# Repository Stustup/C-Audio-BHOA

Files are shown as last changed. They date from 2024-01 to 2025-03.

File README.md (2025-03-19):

# Balanced Headphone Operational Amplifier

A high powered differential headphone amp with a focus on modularity and prototyping. Inspired by the Schiit Audio Magni Heresy.

Picture of the PCB

## Features

- All sections of the amp should be modular (Filter, VA, CA, Output protection)
- All sections should be accessable via pin headers
- Output power >1W per channel

## Schematic

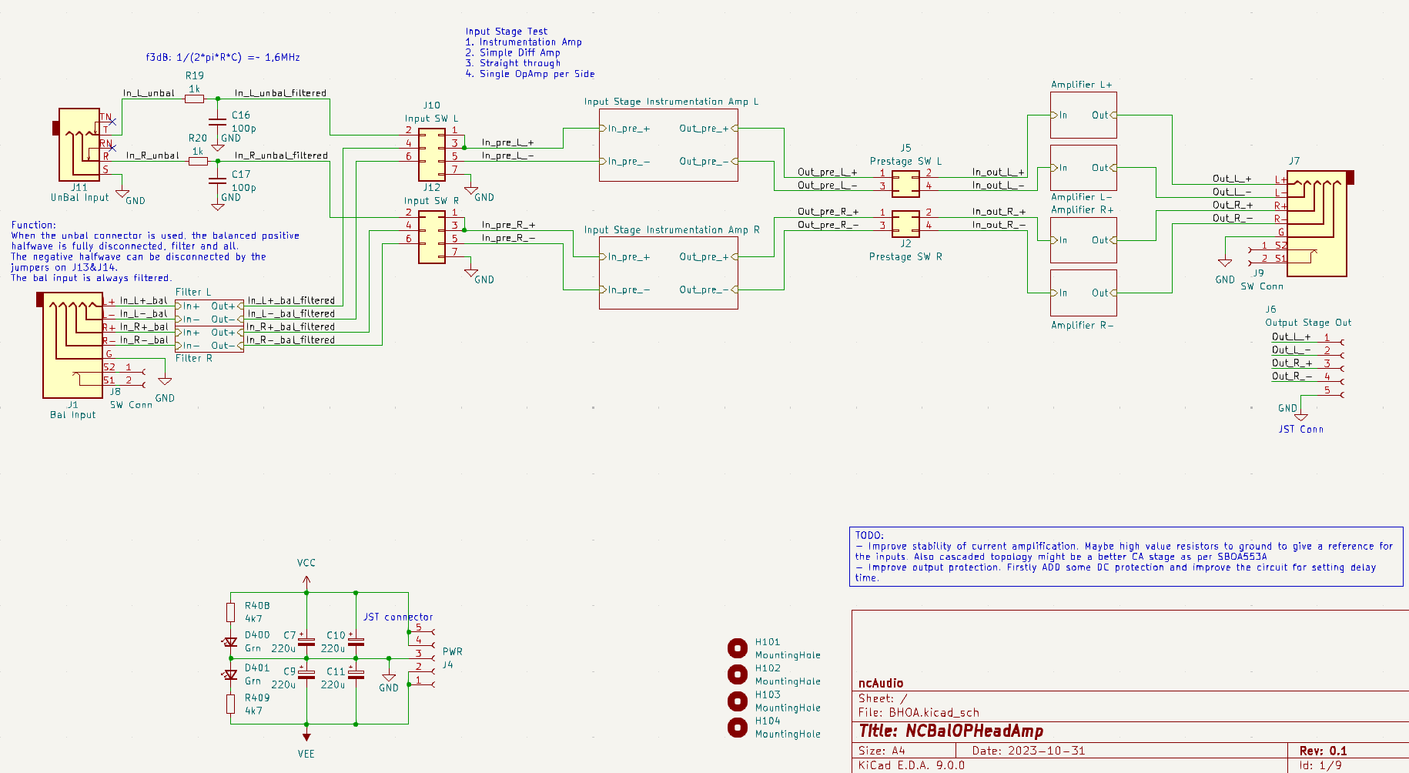
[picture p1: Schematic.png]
Schematic of the Amp


The Amp consists of a simple differential input filter for very high frequency noise, an instrumential amplifier input stage for differential voltage amplification and 8 paralelled opamp sections in buffer topology per channel (of which there are 4 for differential amplification for a total of 16 opamps(!!!). [Mental, I know](http://www.diyaudio.com/archive/blogs/alexcp/attachments/1049d1368388175-ne5532-power-amplifier-ne553205.jpg)). 

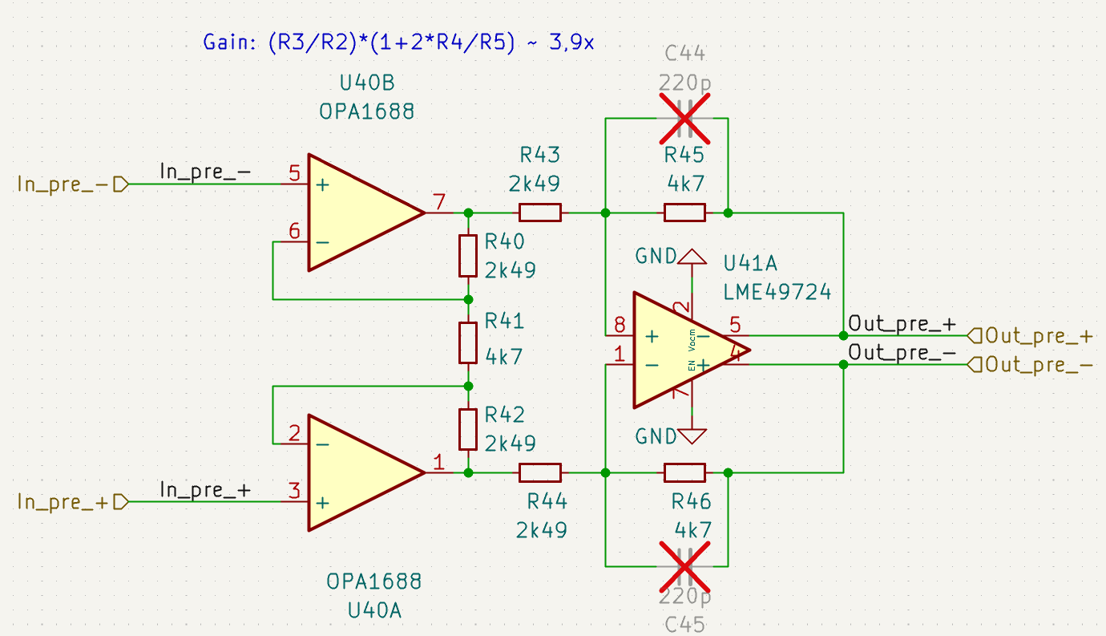
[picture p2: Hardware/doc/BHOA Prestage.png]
Schematic of instrumental amp


The instrumental amplifier in the prestage was chosen, because it is really easy and straight forward to set the gain with just a a single resistor per channel.

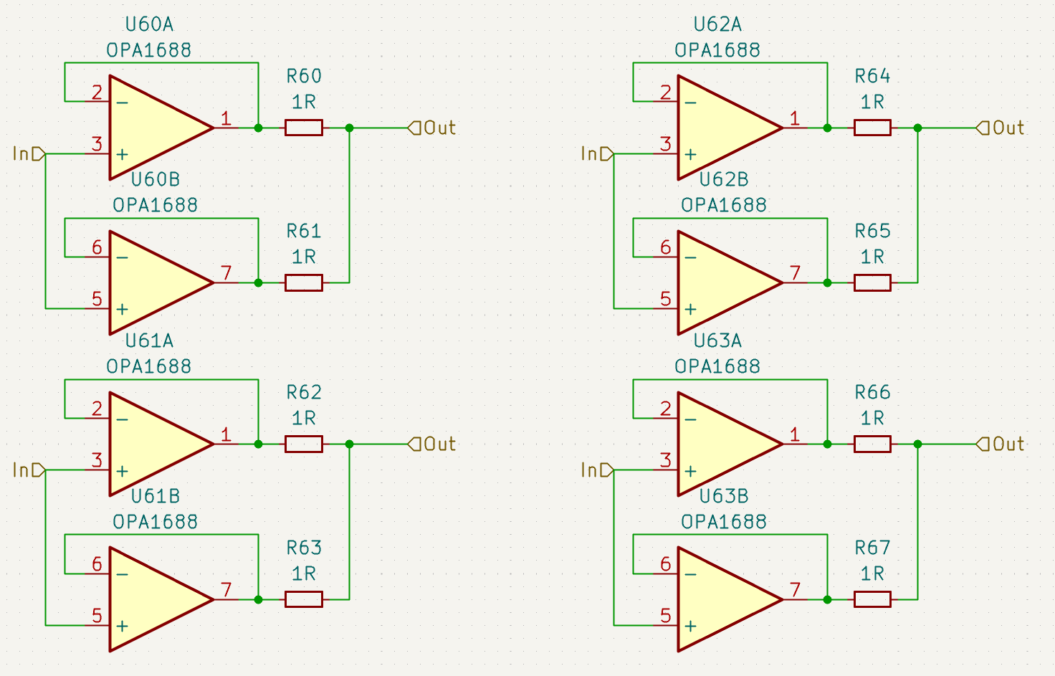
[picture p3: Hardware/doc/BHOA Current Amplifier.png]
Schematic of current amp


Furthermore the output is protected via muting relays driven by a mosfet and a turn on timer for a startup delay. 

The power supply is off board to stay in the limits of JLCPCBs cheap 100x100mm PCB service. It can range from +-5V to +-18V (or how much the Opamps will take). The output relays are 5V, a simple 78l05 so8 IC is supplying them with 5V. 

## TODO

- Improve stability of current amplification. Maybe high value resistors to ground to give a reference for the inputs. Also cascaded topology might be a better CA stage as per [SBOA553A](https://www.ti.com/lit/ab/sboa553a/sboa553a.pdf?ts=1741260128432)
- Improve output protection. Firstly ADD some DC protection and improve the circuit for setting delay time.

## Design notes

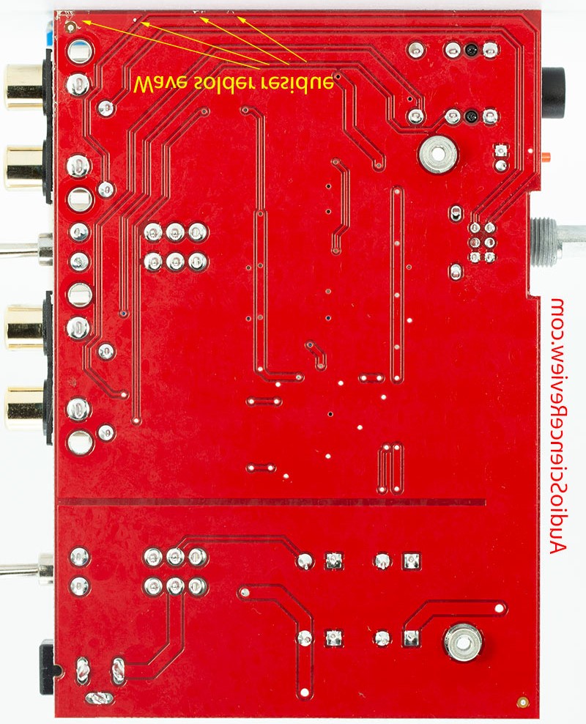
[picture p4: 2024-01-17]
Hardware/doc/Reference Pics Magni 3 Heresy/Schiit Magni Heresy Teardown Back PCB turned.jpg

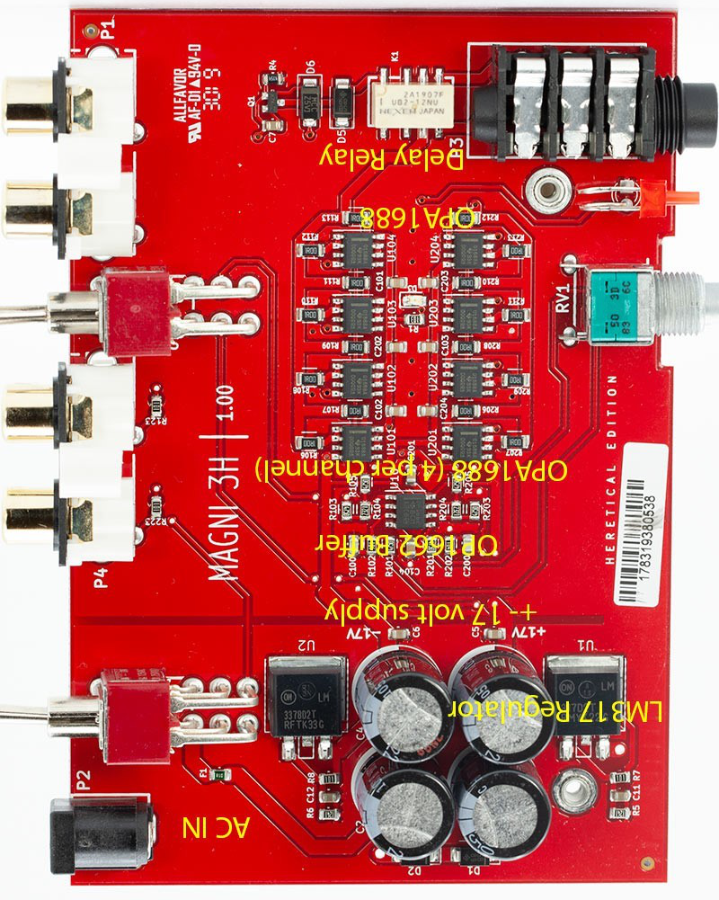
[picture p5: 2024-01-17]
Hardware/doc/Reference Pics Magni 3 Heresy/Schiit Magni Heresy Teardown PCB_turned.jpg

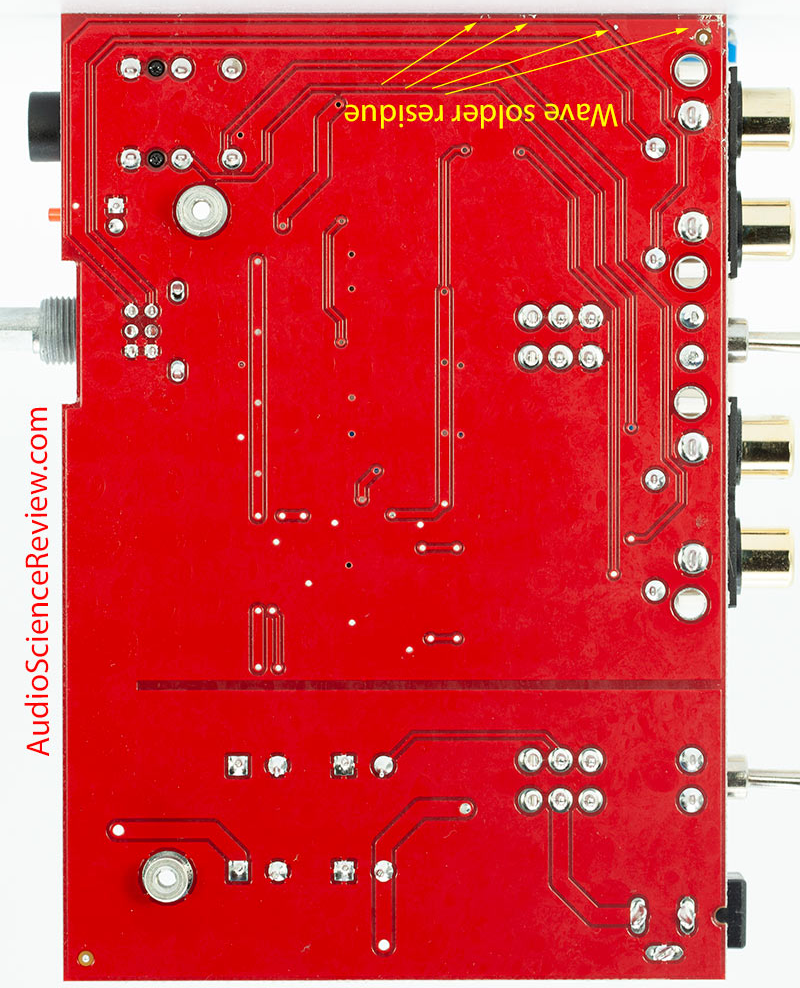
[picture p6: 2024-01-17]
Hardware/doc/Reference Pics Magni 3 Heresy/Schiit Magni Heresy Teardown Back PCB.jpg

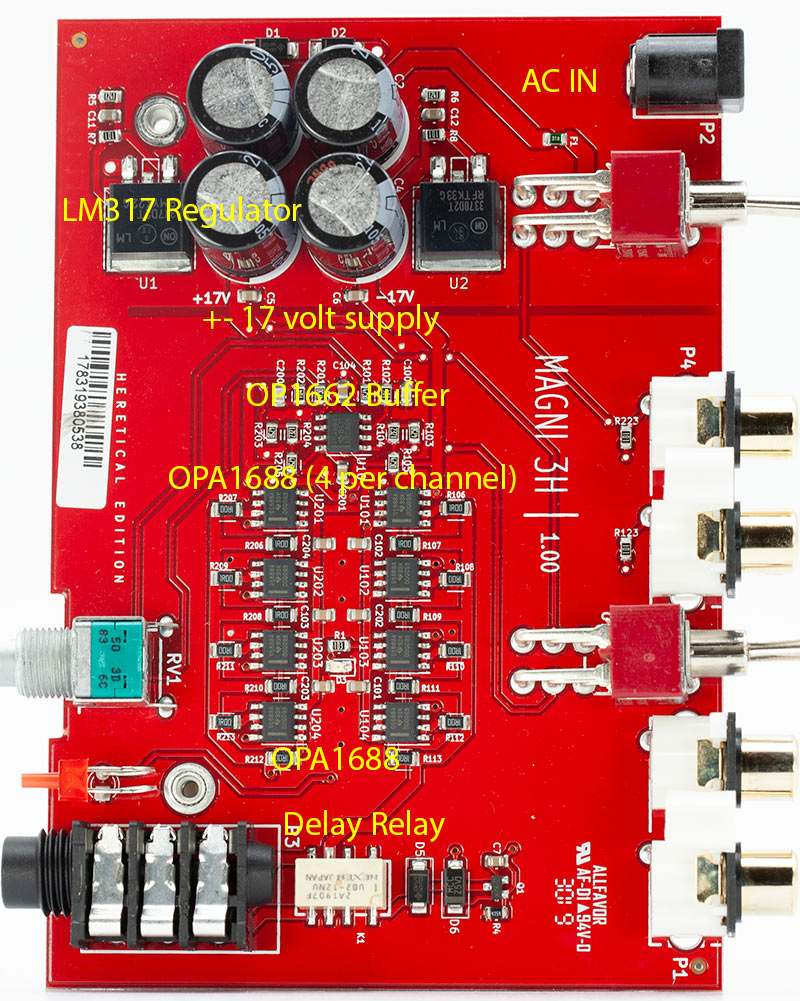
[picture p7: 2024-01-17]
Hardware/doc/Reference Pics Magni 3 Heresy/Schiit Magni Heresy Teardown PCB original.jpg

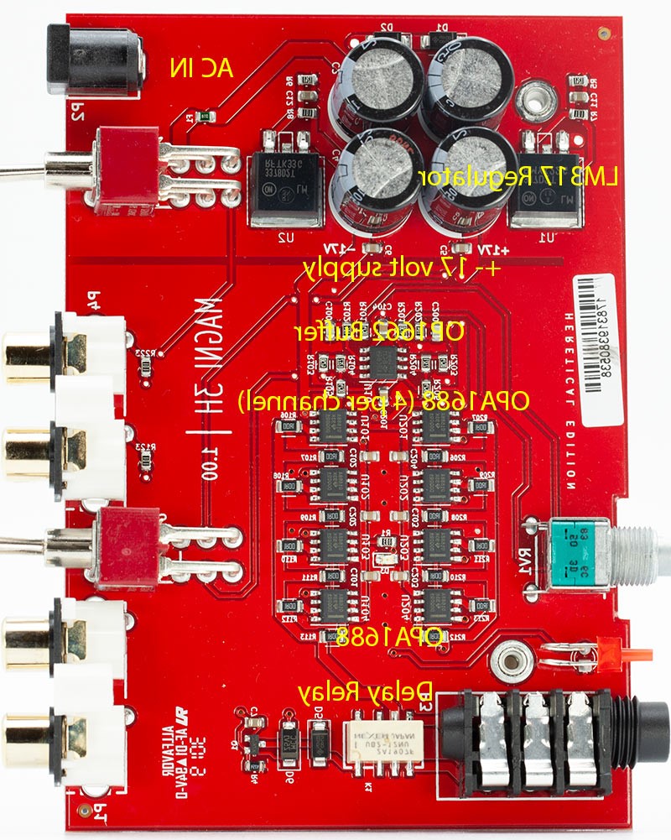
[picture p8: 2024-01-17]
Hardware/doc/Reference Pics Magni 3 Heresy/Schiit Magni Heresy Teardown PCB.jpg

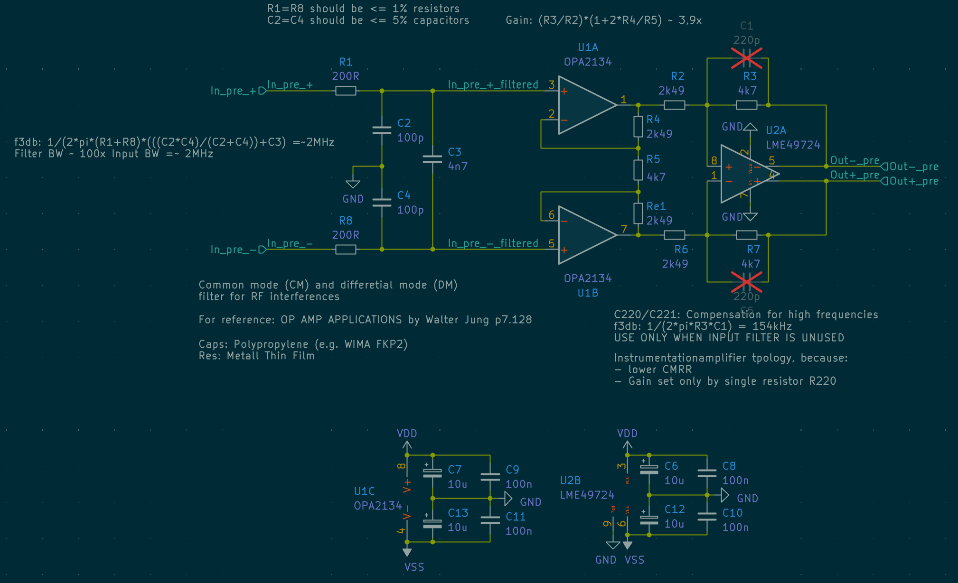
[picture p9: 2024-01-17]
Hardware/KiCAD/BHOA/Filter and Gain Calculation Sample Instrumentation Amp.png

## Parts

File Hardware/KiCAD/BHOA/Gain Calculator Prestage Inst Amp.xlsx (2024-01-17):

Instrumentation Amp Gain Settings
Resistors | R-Values | R-Values round
R3 | 4.7 | 4.7
R2 | 2.49 | 2.49
R4 | 2.49 | 2.49
R5 | 10 | 10
Gain 1 | 1.498 | 1.498
Gain 2 | 1.888 | 1.887550201
Gain overall | 2.828 | 2.827550201

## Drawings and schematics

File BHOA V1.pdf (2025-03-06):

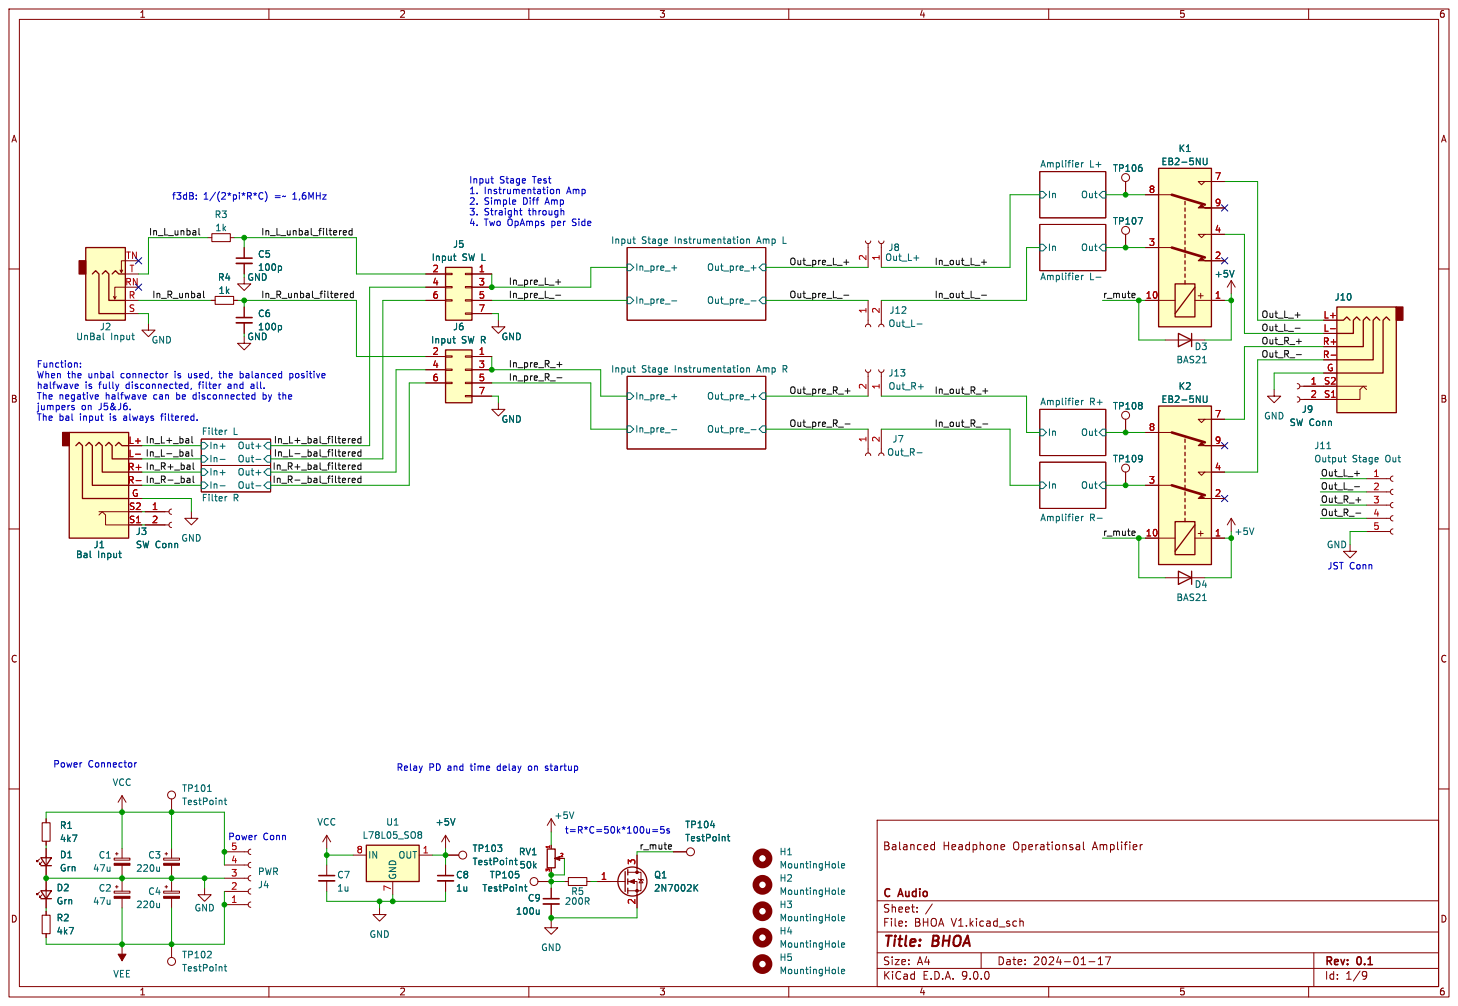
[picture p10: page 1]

TP107 H1 MountingHole H3 MountingHole H4 MountingHole H2 MountingHole H5 MountingHole

4. Two OpAmps per Side Power Connector

J11 Output Stage Out TP103 TestPoint +5V

JST Conn Relay PD and time delay on startup

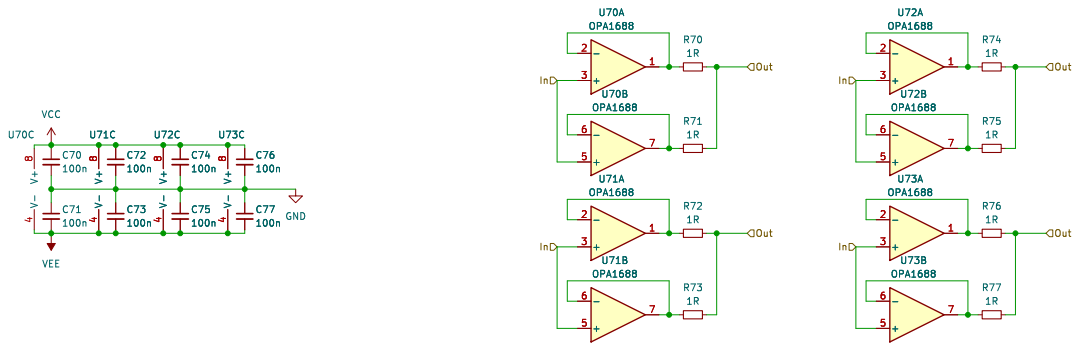
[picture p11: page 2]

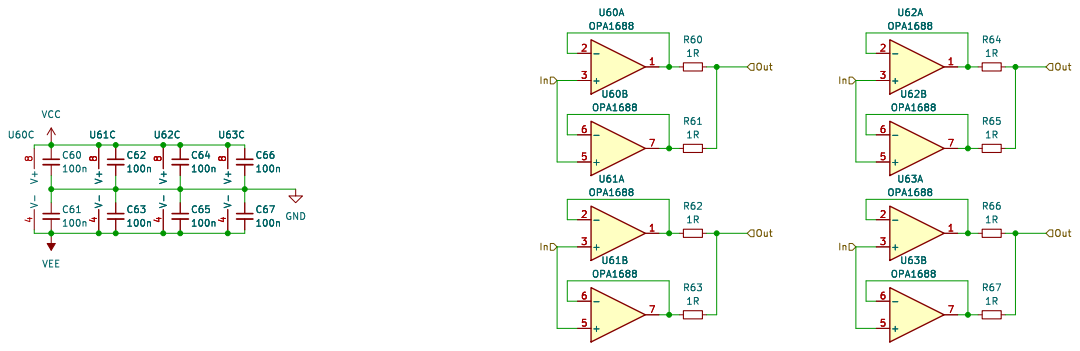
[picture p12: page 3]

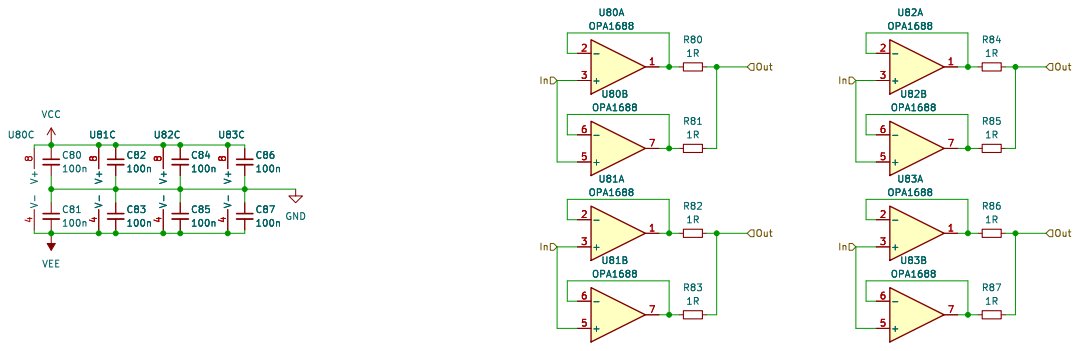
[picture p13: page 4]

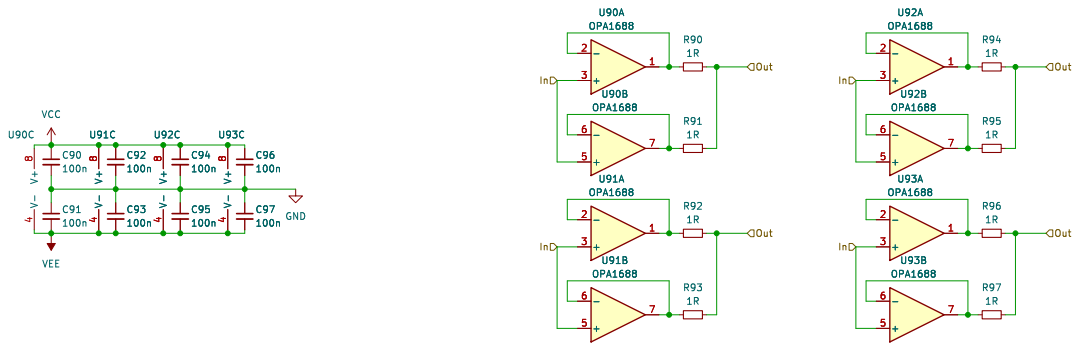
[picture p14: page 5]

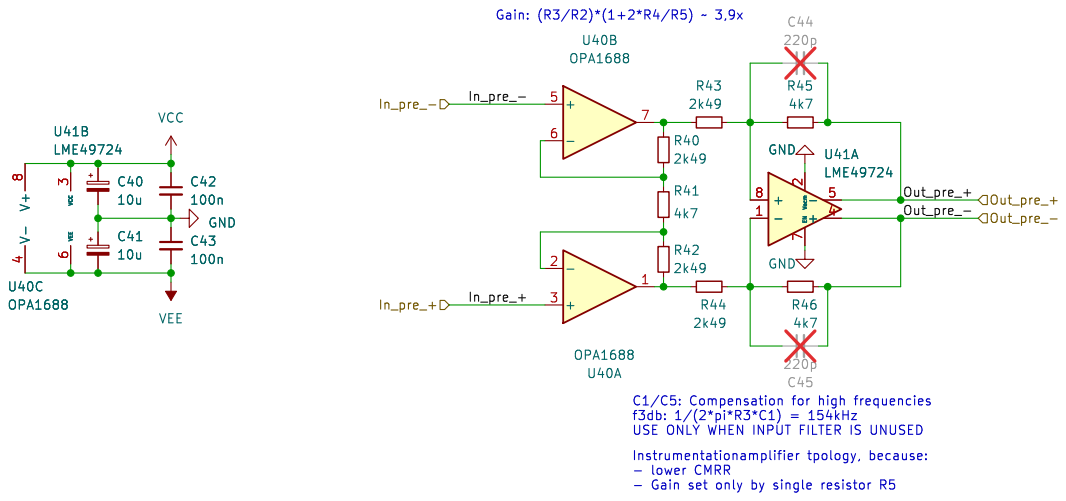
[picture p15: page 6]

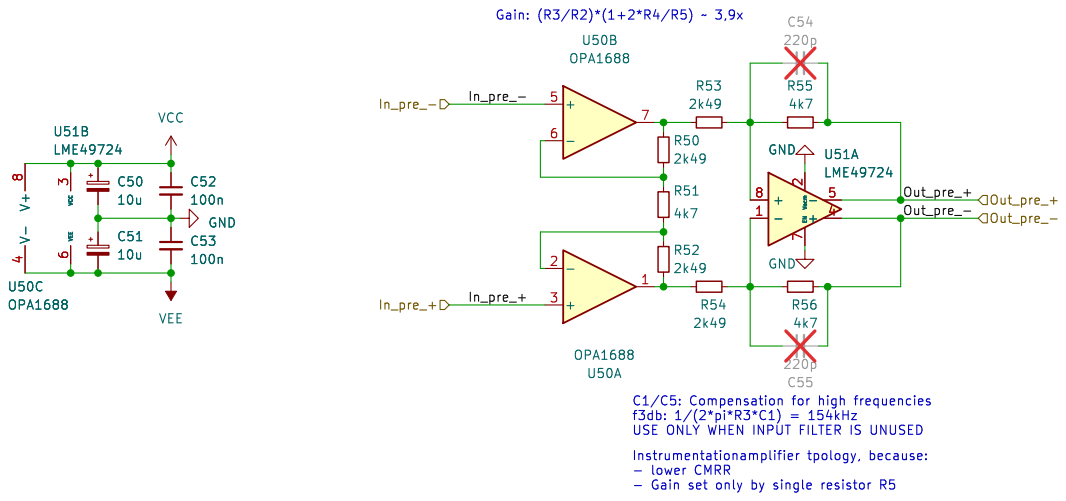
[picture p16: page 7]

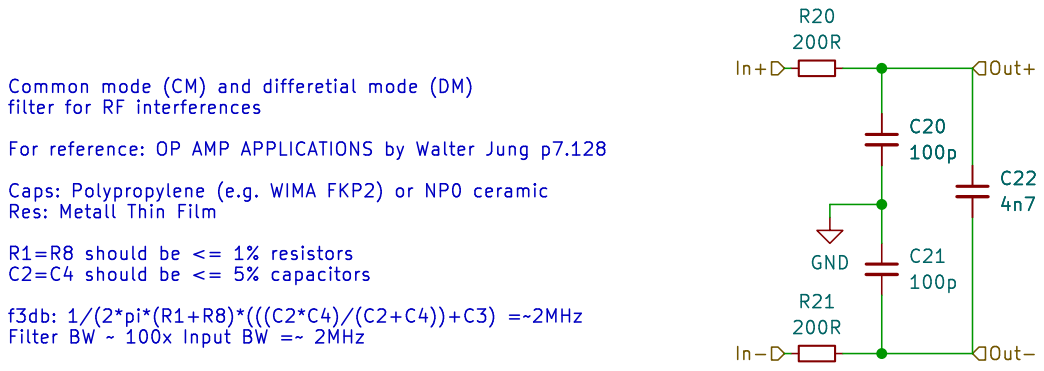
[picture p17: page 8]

R1=R8 should be <= 1% resistors C2=C4 should be <= 5% capacitors

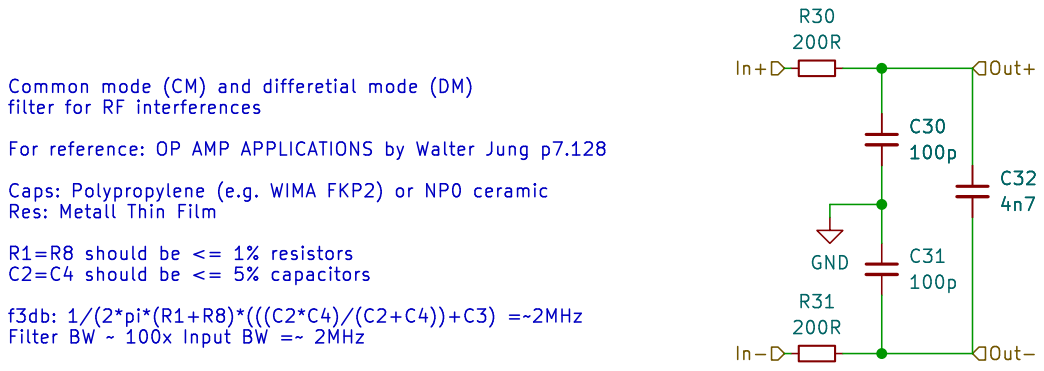
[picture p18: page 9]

R1=R8 should be <= 1% resistors C2=C4 should be <= 5% capacitors

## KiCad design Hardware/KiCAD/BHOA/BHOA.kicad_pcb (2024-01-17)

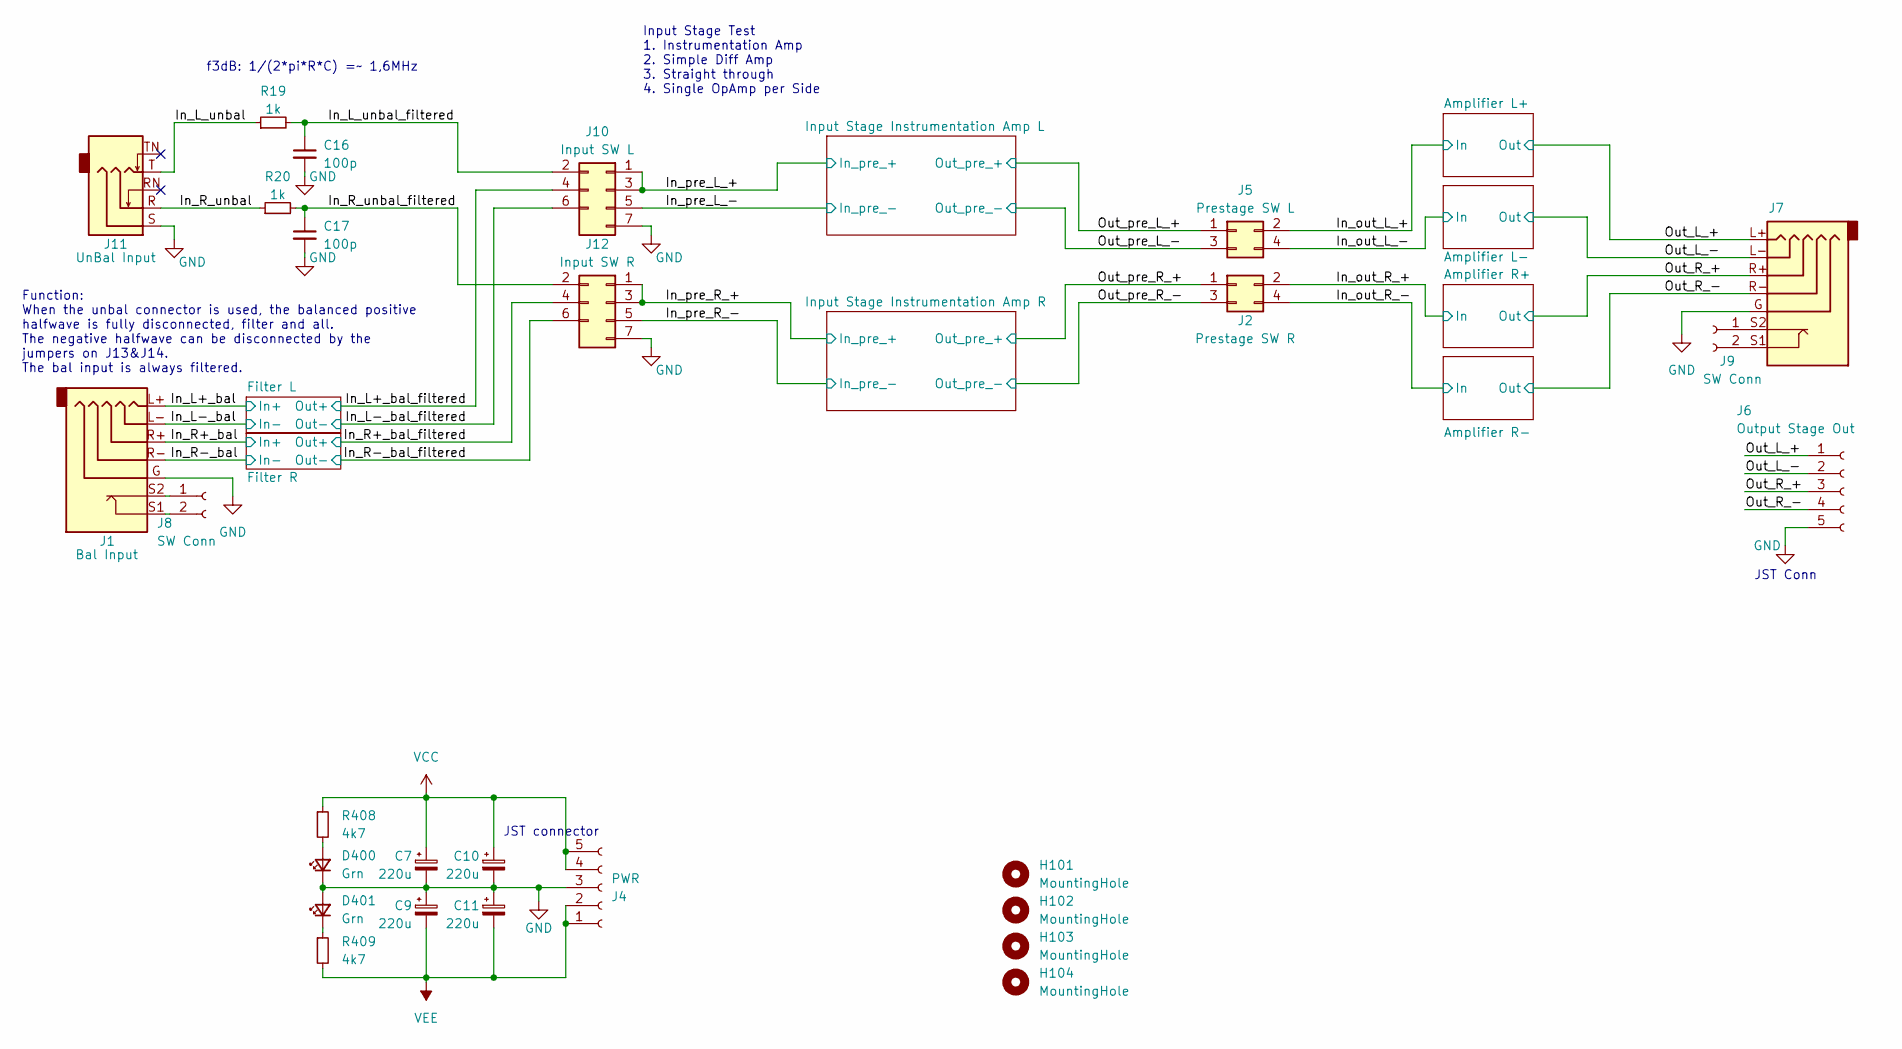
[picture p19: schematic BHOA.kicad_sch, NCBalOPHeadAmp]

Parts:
C7, C9, C10, C11: 220u; CP_Elec_8x10
C16, C17: 100p; C_0805_2012Metric_Pad1.18x1.45mm_HandSolder
D400, D401: Grn; LED_0805_2012Metric_Pad1.15x1.40mm_HandSolder
H101, H102, H103, H104: MountingHole; MountingHole_3.7mm
J1: Bal Input; Pentaconn
J2: Prestage SW R; PinHeader_2x02_P2.54mm_Vertical
J4: PWR; JST_EH_B5B-EH-A_1x05_P2.50mm_Vertical
J5: Prestage SW L; PinHeader_2x02_P2.54mm_Vertical
J6: Output Stage Out; PinSocket_1x05_P2.54mm_Vertical
J7: Pentaconn
J8, J9: SW Conn; PinHeader_1x02_P2.54mm_Vertical
J10: Input SW L; PinHeader_2x04_P2.54mm_Vertical
J11: UnBal Input; Jack_3.5mm_Ledino_KB3SPRS_Horizontal
J12: Input SW R; PinHeader_2x04_P2.54mm_Vertical
R19, R20: 1k; R_0805_2012Metric_Pad1.20x1.40mm_HandSolder
R408, R409: 4k7; R_0805_2012Metric_Pad1.20x1.40mm_HandSolder

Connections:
/In_L+_bal: J1.L+; also elsewhere on the board
/In_L-_bal: J1.L-; also elsewhere on the board
/In_L_unbal: J11.T, R19.1
/In_R+_bal: J1.R+; also elsewhere on the board
/In_R+_bal_filtered: J12.4; also elsewhere on the board
/In_R-_bal: J1.R-; also elsewhere on the board
/In_R-_bal_filtered: J12.6; also elsewhere on the board
/In_R_unbal: J11.R, R20.1
/In_out_L_+: J5.2; also elsewhere on the board
/In_out_L_-: J5.4; also elsewhere on the board
/In_out_R_+: J2.2; also elsewhere on the board
/In_out_R_-: J2.4; also elsewhere on the board
/In_pre_L_+: J10.1, J10.3; also elsewhere on the board
/In_pre_L_-: J10.5; also elsewhere on the board
/In_pre_R_+: J12.1, J12.3; also elsewhere on the board
/In_pre_R_-: J12.5; also elsewhere on the board
/Out_L_+: J6.1, J7.L+; also elsewhere on the board
/Out_L_-: J6.2, J7.L-; also elsewhere on the board
/Out_R_+: J6.3, J7.R+; also elsewhere on the board
/Out_R_-: J6.4, J7.R-; also elsewhere on the board
/Out_pre_L_+: J5.1; also elsewhere on the board
/Out_pre_L_-: J5.3; also elsewhere on the board
/Out_pre_R_+: J2.1; also elsewhere on the board
/Out_pre_R_-: J2.3; also elsewhere on the board
unnamed: D400.2 (A), R408.2
unnamed: D401.1 (K), R409.1
unnamed: J1.S2, J8.1
unnamed: J1.S1, J8.2
unnamed: J7.S2, J9.1
unnamed: J7.S1, J9.2
VCC: C7.1, C10.1, J4.4, J4.5, R408.1; also elsewhere on the board
VEE: C9.2, C11.2, J4.1, J4.2, R409.2; also elsewhere on the board

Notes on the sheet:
JST Conn
JST connector
Function: When the unbal connector is used, the balanced positive halfwave is fully disconnected, filter and all. The negative halfwave can be disconnected by the jumpers on J13&J14. The bal input is always filtered.
f3dB: 1/(2*pi*R*C) =~ 1,6MHz
Input Stage Test 1. Instrumentation Amp 2. Simple Diff Amp 3. Straight through 4. Single OpAmp per Side

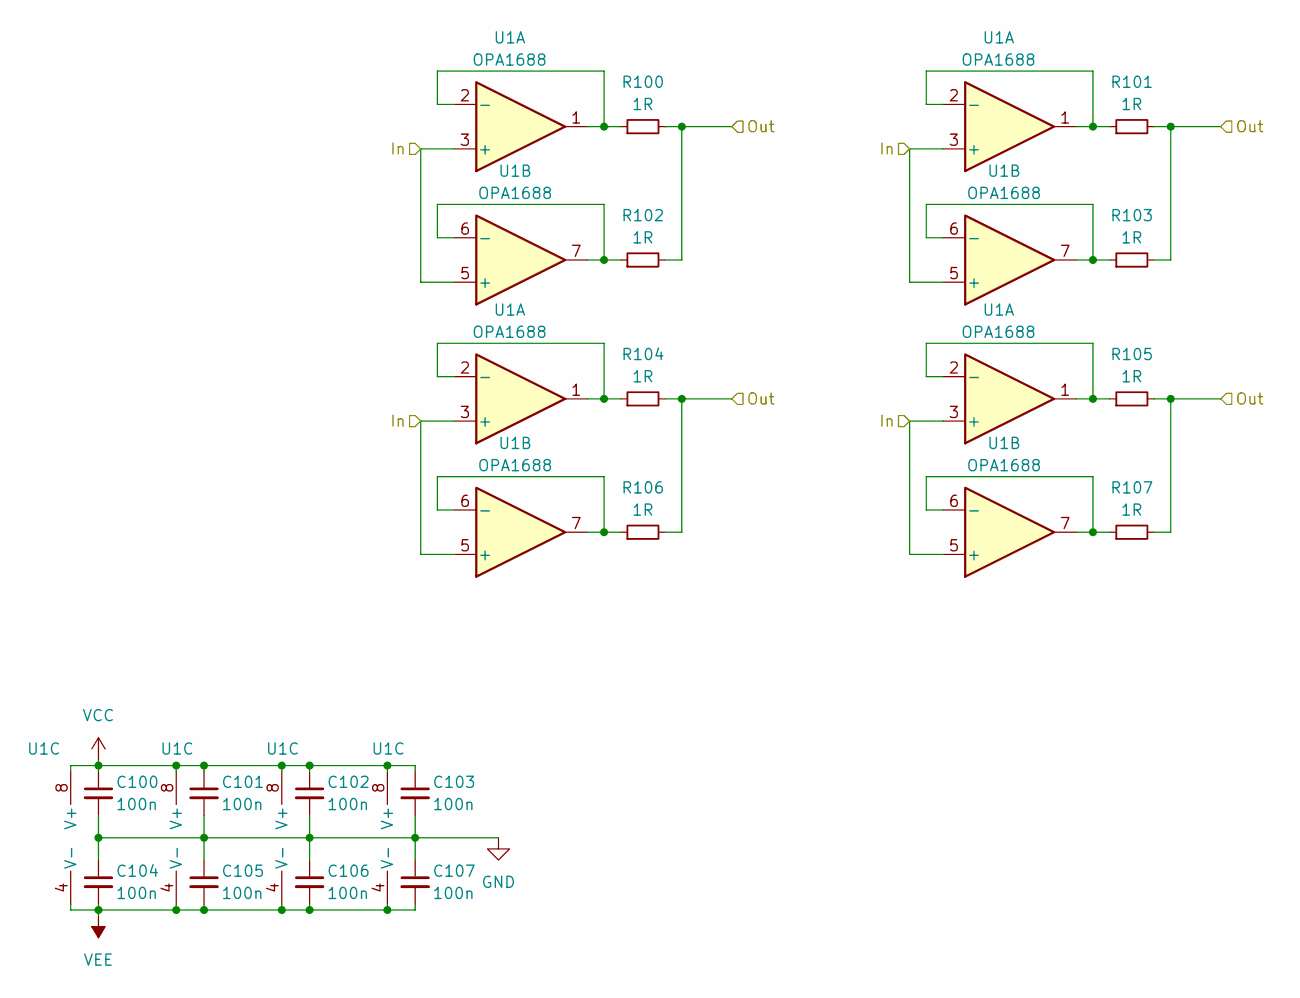
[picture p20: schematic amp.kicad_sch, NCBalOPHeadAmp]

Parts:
C100, C101, C102, C103, C104, C105, C106, C107: 100n; C_0805_2012Metric_Pad1.18x1.45mm_HandSolder
R100, R101, R102, R103, R104, R105, R106, R107: 1R; R_1206_3216Metric_Pad1.30x1.75mm_HandSolder
U1: OPA1688; SOIC-8_3.9x4.9mm_P1.27mm

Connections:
/Out_L_-: R100.2, R101.2, R102.2, R103.2, R104.2, R105.2, R106.2, R107.2; also elsewhere on the board
unnamed 38: R100.1; also elsewhere on the board
unnamed 39: R102.1; also elsewhere on the board
unnamed 40: R101.1; also elsewhere on the board
unnamed 41: R103.1; also elsewhere on the board
unnamed 42: R104.1; also elsewhere on the board
unnamed 43: R106.1; also elsewhere on the board
unnamed 44: R105.1; also elsewhere on the board
unnamed 45: R107.1; also elsewhere on the board
VCC: C100.1, C101.1, C102.1, C103.1; also elsewhere on the board
VEE: C104.2, C105.2, C106.2, C107.2; also elsewhere on the board

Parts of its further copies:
C200, C201, C202, C203, C204, C205, C206, C207, C300, C301, C302, C303, C304, C305, C306, C307, C400, C401, C402, C403, C404, C405, C406, C407: 100n; C_0805_2012Metric_Pad1.18x1.45mm_HandSolder
R200, R201, R202, R203, R204, R205, R206, R207, R300, R301, R302, R303, R304, R305, R306, R307, R400, R401, R402, R403, R404, R405, R406, R407: 1R; R_1206_3216Metric_Pad1.30x1.75mm_HandSolder
U100, U101, U102, U103, U200, U201, U202, U203, U300, U301, U302, U303, U400, U401, U402, U403: OPA1688; SOIC-8_3.9x4.9mm_P1.27mm

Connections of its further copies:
/In_out_L_+: U200.3 (+), U200.5 (+), U201.3 (+), U201.5 (+), U202.3 (+), U202.5 (+), U203.3 (+), U203.5 (+); also elsewhere on the board
/In_out_L_-: U100.3 (+), U100.5 (+), U101.3 (+), U101.5 (+), U102.3 (+), U102.5 (+), U103.3 (+), U103.5 (+); also elsewhere on the board
/In_out_R_+: U300.3 (+), U300.5 (+), U301.3 (+), U301.5 (+), U302.3 (+), U302.5 (+), U303.3 (+), U303.5 (+); also elsewhere on the board
/In_out_R_-: U400.3 (+), U400.5 (+), U401.3 (+), U401.5 (+), U402.3 (+), U402.5 (+), U403.3 (+), U403.5 (+); also elsewhere on the board
/Out_L_+: R200.2, R201.2, R202.2, R203.2, R204.2, R205.2, R206.2, R207.2; also elsewhere on the board
/Out_R_+: R300.2, R301.2, R302.2, R303.2, R304.2, R305.2, R306.2, R307.2; also elsewhere on the board
/Out_R_-: R400.2, R401.2, R402.2, R403.2, R404.2, R405.2, R406.2, R407.2; also elsewhere on the board
unnamed 38: U100.1, U100.2 (-); also elsewhere on the board
unnamed 39: U100.6 (-), U100.7; also elsewhere on the board
unnamed 40: U101.1, U101.2 (-); also elsewhere on the board
unnamed 41: U101.6 (-), U101.7; also elsewhere on the board
unnamed 42: U102.1, U102.2 (-); also elsewhere on the board
unnamed 43: U102.6 (-), U102.7; also elsewhere on the board
unnamed 44: U103.1, U103.2 (-); also elsewhere on the board
unnamed 45: U103.6 (-), U103.7; also elsewhere on the board
unnamed: R200.1, U200.1, U200.2 (-)
unnamed: R202.1, U200.6 (-), U200.7
unnamed: R201.1, U201.1, U201.2 (-)
unnamed: R203.1, U201.6 (-), U201.7
unnamed: R204.1, U202.1, U202.2 (-)
unnamed: R206.1, U202.6 (-), U202.7
unnamed: R205.1, U203.1, U203.2 (-)
unnamed: R207.1, U203.6 (-), U203.7
unnamed: R300.1, U300.1, U300.2 (-)
unnamed: R302.1, U300.6 (-), U300.7
unnamed: R301.1, U301.1, U301.2 (-)
unnamed: R303.1, U301.6 (-), U301.7
unnamed: R304.1, U302.1, U302.2 (-)
unnamed: R306.1, U302.6 (-), U302.7
unnamed: R305.1, U303.1, U303.2 (-)
unnamed: R307.1, U303.6 (-), U303.7
unnamed: R400.1, U400.1, U400.2 (-)
unnamed: R402.1, U400.6 (-), U400.7
unnamed: R401.1, U401.1, U401.2 (-)
unnamed: R403.1, U401.6 (-), U401.7
unnamed: R404.1, U402.1, U402.2 (-)
unnamed: R406.1, U402.6 (-), U402.7
unnamed: R405.1, U403.1, U403.2 (-)
unnamed: R407.1, U403.6 (-), U403.7
VCC: C200.1, C201.1, C202.1, C203.1, C300.1, C301.1, C302.1, C303.1, C400.1, C401.1, C402.1, C403.1, U100.8 (V+), U101.8 (V+), U102.8 (V+), U103.8 (V+), U200.8 (V+), U201.8 (V+), U202.8 (V+), U203.8 (V+), U300.8 (V+), U301.8 (V+), U302.8 (V+), U303.8 (V+), U400.8 (V+), U401.8 (V+), U402.8 (V+), U403.8 (V+); also elsewhere on the board
VEE: C204.2, C205.2, C206.2, C207.2, C304.2, C305.2, C306.2, C307.2, C404.2, C405.2, C406.2, C407.2, U100.4 (V-), U101.4 (V-), U102.4 (V-), U103.4 (V-), U200.4 (V-), U201.4 (V-), U202.4 (V-), U203.4 (V-), U300.4 (V-), U301.4 (V-), U302.4 (V-), U303.4 (V-), U400.4 (V-), U401.4 (V-), U402.4 (V-), U403.4 (V-); also elsewhere on the board

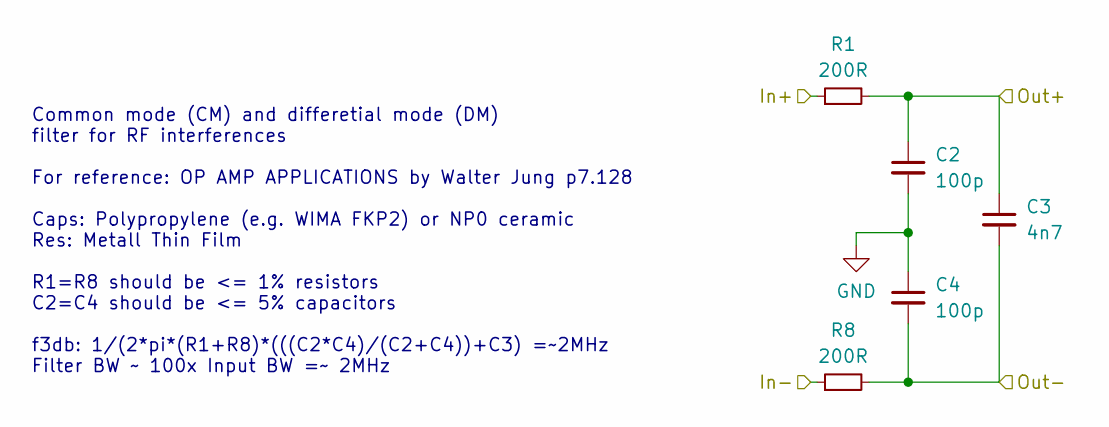
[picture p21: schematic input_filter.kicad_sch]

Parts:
C2, C4: 100p; C_0805_2012Metric_Pad1.18x1.45mm_HandSolder
C3: 4n7; C_0805_2012Metric_Pad1.18x1.45mm_HandSolder
R1, R8: 200R; R_0805_2012Metric_Pad1.20x1.40mm_HandSolder

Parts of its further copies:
C801, C803, C901, C903: 100p; C_0805_2012Metric_Pad1.18x1.45mm_HandSolder
C802, C902: 4n7; C_0805_2012Metric_Pad1.18x1.45mm_HandSolder
R801, R802, R901, R902: 200R; R_0805_2012Metric_Pad1.20x1.40mm_HandSolder

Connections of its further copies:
/In_L+_bal: R801.1; also elsewhere on the board
/In_L-_bal: R802.1; also elsewhere on the board
/In_R+_bal: R901.1; also elsewhere on the board
/In_R+_bal_filtered: C901.1, C902.1, R901.2; also elsewhere on the board
/In_R-_bal: R902.1; also elsewhere on the board
/In_R-_bal_filtered: C902.2, C903.2, R902.2; also elsewhere on the board

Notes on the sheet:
Common mode (CM) and differetial mode (DM) filter for RF interferences For reference: OP AMP APPLICATIONS by Walter Jung p7.128 Caps: Polypropylene (e.g. WIMA FKP2) or NP0 ceramic Res: Metall Thin Film R1=R8 should be <= 1% resistors C2=C4 should be <= 5% capacitors f3db: 1/(2*pi*(R1+R8)*(((C2*C4)/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

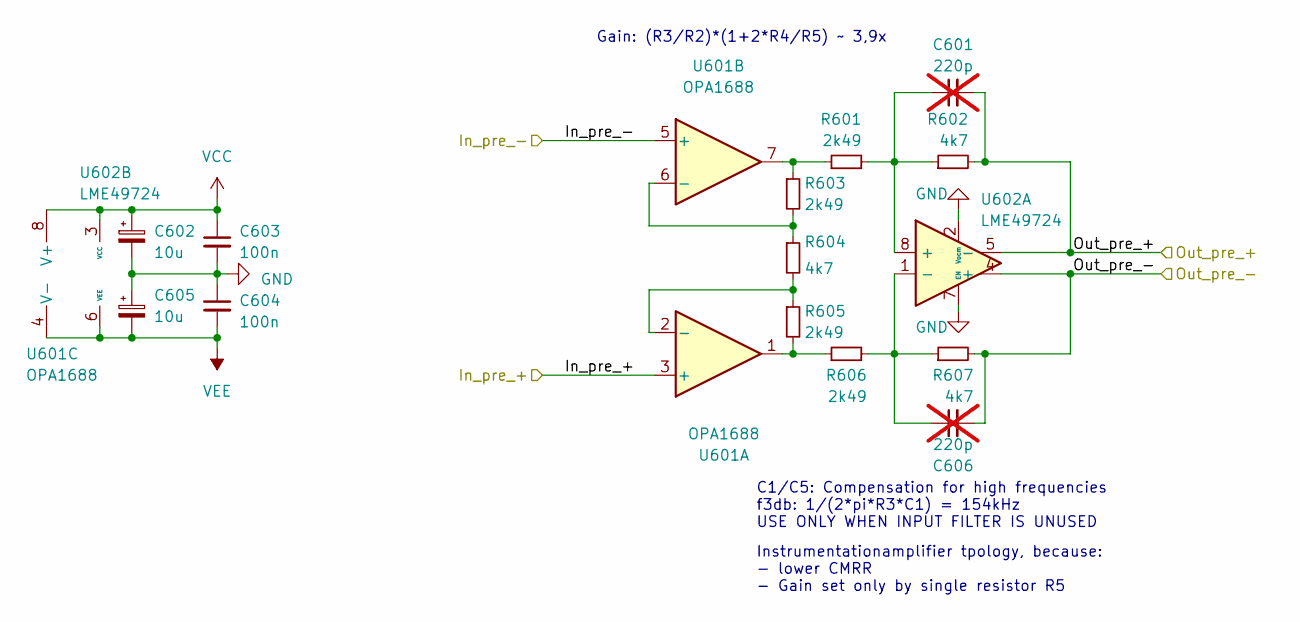
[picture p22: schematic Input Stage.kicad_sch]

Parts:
C601, C606: 220p; C_0805_2012Metric_Pad1.18x1.45mm_HandSolder; not fitted
C602, C605: 10u; C_1206_3216Metric_Pad1.33x1.80mm_HandSolder
C603, C604: 100n; C_0805_2012Metric_Pad1.18x1.45mm_HandSolder
R601, R603, R605, R606: 2k49; R_0805_2012Metric_Pad1.20x1.40mm_HandSolder
R602, R607: 4k7; R_0805_2012Metric_Pad1.20x1.40mm_HandSolder
R604: 4k7; R_1206_3216Metric_Pad1.30x1.75mm_HandSolder
U601: OPA1688; SOIC-8_3.9x4.9mm_P1.27mm
U602: LME49724; SOIC-8_3.9x4.9mm_P1.27mm

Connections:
/In_pre_L_+: U601.3 (+); also elsewhere on the board
/In_pre_L_-: U601.5 (+); also elsewhere on the board
/Out_pre_L_+: C601.2, R602.2, U602.5 (-); also elsewhere on the board
/Out_pre_L_-: C606.2, R607.2, U602.4 (+); also elsewhere on the board
unnamed: C601.1, R601.2, R602.1, U602.8 (+)
unnamed: C606.1, R606.2, R607.1, U602.1 (-)
unnamed: R601.1, R603.1, U601.7
unnamed: R605.2, R606.1, U601.1
unnamed: R604.2, R605.1, U601.2 (-)
unnamed: R603.2, R604.1, U601.6 (-)
VCC: C602.1, C603.1, U601.8 (V+), U602.3 (VCC); also elsewhere on the board
VEE: C604.2, C605.2, U601.4 (V-), U602.6 (VEE); also elsewhere on the board

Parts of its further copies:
C701, C706: 220p; C_0805_2012Metric_Pad1.18x1.45mm_HandSolder; not fitted
C702, C705: 10u; C_1206_3216Metric_Pad1.33x1.80mm_HandSolder
C703, C704: 100n; C_0805_2012Metric_Pad1.18x1.45mm_HandSolder
R701, R703, R705, R706: 2k49; R_0805_2012Metric_Pad1.20x1.40mm_HandSolder
R702, R707: 4k7; R_0805_2012Metric_Pad1.20x1.40mm_HandSolder
R704: 4k7; R_1206_3216Metric_Pad1.30x1.75mm_HandSolder
U701: OPA1688; SOIC-8_3.9x4.9mm_P1.27mm
U702: LME49724; SOIC-8_3.9x4.9mm_P1.27mm

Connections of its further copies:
/In_pre_R_+: U701.3 (+); also elsewhere on the board
/In_pre_R_-: U701.5 (+); also elsewhere on the board
/Out_pre_R_+: C701.2, R702.2, U702.5 (-); also elsewhere on the board
/Out_pre_R_-: C706.2, R707.2, U702.4 (+); also elsewhere on the board
unnamed: C701.1, R701.2, R702.1, U702.8 (+)
unnamed: C706.1, R706.2, R707.1, U702.1 (-)
unnamed: R701.1, R703.1, U701.7
unnamed: R705.2, R706.1, U701.1
unnamed: R704.2, R705.1, U701.2 (-)
unnamed: R703.2, R704.1, U701.6 (-)
VCC: C702.1, C703.1, U701.8 (V+), U702.3 (VCC); also elsewhere on the board
VEE: C704.2, C705.2, U701.4 (V-), U702.6 (VEE); also elsewhere on the board

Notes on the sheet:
C1/C5: Compensation for high frequencies f3db: 1/(2*pi*R3*C1) = 154kHz USE ONLY WHEN INPUT FILTER IS UNUSED
Instrumentationamplifier tpology, because: - lower CMRR - Gain set only by single resistor R5
Gain: (R3/R2)*(1+2*R4/R5) ~ 3,9x

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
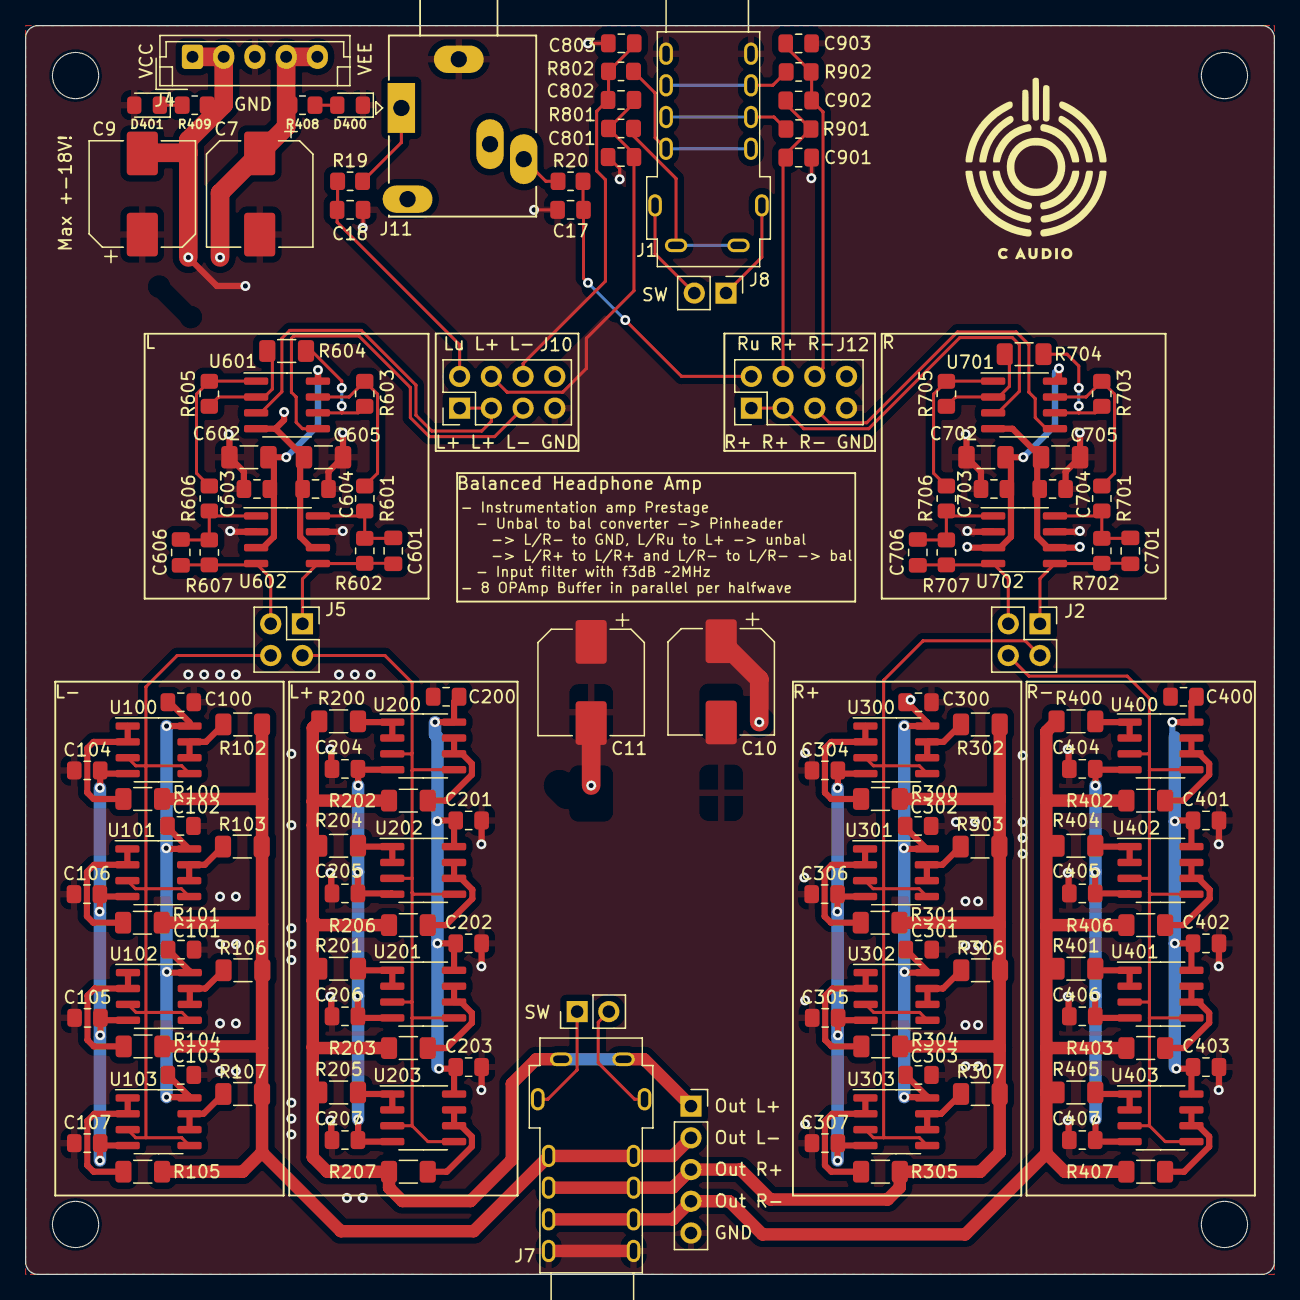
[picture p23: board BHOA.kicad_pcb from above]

Board: 4 copper layers, 100.0 x 100.0 mm, 147 parts (0 on the bottom side), 81 nets.

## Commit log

2024-01-17 added the project
    [BHOA-B_Cu.gbr, BHOA-B_Mask.gbr, BHOA-B_Paste.gbr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]
2024-01-17 changed logo to c audio
    [BHOA.kicad_pcb, BHOA.kicad_sch, Input Stage.kicad_sch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]
2025-03-06 added schematic pic
    [BHOA.kicad_sch, Input Stage.kicad_sch, amp.kicad_sch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]
2025-03-06 added schematic to readme
